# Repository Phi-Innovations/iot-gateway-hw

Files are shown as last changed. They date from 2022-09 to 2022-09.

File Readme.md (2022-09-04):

# IOT-GATEWAY-HW

This project contains the hardware design files of the IoT Gateway designed by PHI Innovations.

The hardware was designed using [Altium Designer](www.altium.com) tool.

# Features

* CPU: STM32F417VET6 Microncontroller
* 1 MB Dataflash
* MMC card support
* Debug UART interface
* 1 RS-485 interface
* 1 USB interface
* 1 Ethernet interface
* 1 WiFi module (ESP8266)
* 1 2G Modem (Sierra Wireless HL6528)
* 2 Digital inputs
* 2 Analog inputs (4-20 mA)
* 1 radio interface (never tested)

# TODO

- [ ] Improve documentation
- [ ] Add reset connection between CPU and the WiFi module

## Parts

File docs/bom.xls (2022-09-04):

BOM |  | PHI_IOT_GATEWAY_V1.3.PrjPcb |  | VER: | 08/03/2018
Item | Quantity | Designator | Comment | P Description | Fabricante 1 | Partnumber fabricante 1 | Partnumber Alternativo | PCB Info
1 | 1 | ANT1 | COAX-F | CONN SMA JACK R/A 50 OHM PCB | TE Connectivity AMP Connectors | 5-1814400-1
2 | 1 | ANT2 | 0915AT43A0026E | 915MHz Chip RF Antenna 902MHz ~ 928MHz | Johanson Technology Inc | 0915AT43A0026E
3 | 1 | ANT3 | U.FL RECEPTACLE | RECPT ULTRA-MINI COAX SMD | Hirose | U.FL-R-SMT-1
4 | 1 | BAT1 | BS-3 | HOLDER COINCELL 2032 RETAINR ARM | MPD | BS-3
5 | 27 | C2, C5, C6, C9, C10, C11, C12, C13, C14, C17, C21, C22, C27, C34, C39, C41, C47, C53, C54, C56, C58, C60, C61, C63, C64, C149, C162 | 0.1uF | Capacitor ceramico 0603 0.1uF 20% 50V X7R | AVX Corporation | 06035C104JAT2A | ‎C1608X5R1H104K080AA
6 | 8 | C3, C4, C15, C52, C65, C68, C77, C81 | 18pF | Capacitor ceramico 0603 18pF 5% 50V C0G | Murata Electronics North America | GRM1885C1H180JA01D
7 | 2 | C7, C8 | 2.2uF | Capacitor ceramico 0603 1uF 5% 25V X5R | Murata Electronics North America | GRM188R61E225MA12D
8 | 2 | C16, C18 | 0.01uF | Capacitor ceramico 0603 10000pF 10% 50V X7R | Kemet | C0603C103K5RACTU
9 | 2 | C19, C20 | 0.01uF | Capacitor ceramico 0603 10000pF 10% 50V X7R | Kemet | C0603C103K5RACTU |  | DNP
10 | 4 | C23, C24, C78, C83 | 1.5pF | Capacitor ceramico 0402 2.2pF 5% 50V C0G | Murata Electronics North America | GRM1555C1H1R5CA01D
11 | 2 | C25, C26 | 680uF 35V | CAP ALUM 680UF 20% 35V RADIAL | NIC Components Corp. | NREHL681M35V10x28F | UHW1V681MPD6
12 | 10 | C28, C29, C48, C50, C62, C123, C124, C150, C165, C167 | 10uF | Capacitor ceramico 0805 10uF 10% 10V X5R | AVX Corporation | 0805ZD106MAT2A | CL21A106KOQNNNE
13 | 11 | C30, C31, C32, C33, C35, C36, C37, C38, C163, C164, C166 | 33pF | Capacitor ceramico 0603 33pF 10% 50V C0G | Murata Electronics North America | GRM1885C1H330JA01D
14 | 1 | C40 | 0.015uF | Capacitor ceramico 0603 0.015uF 10% 50V X7R | Samsung Electro-Mechanics America, Inc | CL10B153KB8SFNC
15 | 5 | C42, C46, C70, C72, C85 | 0.47uF | Capacitor ceramico 0402 0.47uF 10% 10V X5R | Murata Electronics North America | GRM155R61A474KE15D | LMK105BJ474KV-F
16 | 2 | C43, C57 | 4.7uF | Capacitor ceramico 0603 4.7uF 10% 16V X7R | Samsung Electro-Mechanics America, Inc | CL10A475KO8NNNC
17 | 4 | C44, C75, C88, C90 | 0.15uF | Capacitor ceramico 0402 0.15uF 10% 10V X5R | Murata Electronics North America | GRM155R61A154KE19D | CGA2B3X5R1A154M050BB
18 | 12 | C45, C69, C71, C73, C74, C79, C80, C82, C84, C86, C89, C91 | 100pF | Capacitor ceramico 0402 100pF 5% 16V C0G | Murata Electronics North America | GRM1555C1H101JA01D | C0402C101J3GACTU
19 | 4 | C49, C59, C67, C76 | 1uF | Capacitor ceramico 0603 1uF 5% 25V X5R | Murata Electronics North America | GRM188R61E105KA12D
20 | 2 | C66, C87 | 470pF | Capacitor ceramico 0603 470pF 10% 50V X7R | Kemet | C0603C471K5RACTU
21 | 1 | C92 | 1.2pF | Capacitor ceramico 0402 1.2pF 20% 50V C0G | Murata Electronics North America | GRM1555C1H1R2CA01D
22 | 1 | C93 | 3.9pF | Capacitor ceramico 0402 3.9pF 2% 50V C0G | Murata Electronics North America | GJM1555C1H3R9BB01D
23 | 1 | C94 | 5.6pF | Capacitor ceramico 0402 5.6pF 5% 50V C0G | Murata Electronics North America | GRM1555C1H5R6CA01J
24 | 1 | C95 | 2.7pF | Capacitor ceramico 0402 2.7pF 5% 16V C0H | Samsung Electro-Mechanics America, Inc. | CL05C2R7CB5NNNC
25 | 1 | C97 | 0.5pF | Capacitor ceramico 0402 0.5pF 20% 50V C0G | Murata Electronics North America | GRM1555C1HR50BA01D
26 | 1 | C161 | 220uF 16V | CAP ALUM 220UF 20% 16V RADIAL | EPCOS | B41827A4227M007 | UVY1C221MED1TD
27 | 1 | CN1 | BLOCK - 5POS | TERM BLOCK HDR 5POS 90DEG 3.81MM | On Shore Technology Inc. | OSTOQ053251
28 | 1 | CN3 | BLOCK - 8POS | TERM BLOCK HDR 8POS 90DEG 3.81MM | On Shore Technology Inc. | OSTOQ083251
29 | 1 | CN4 | BLOCK - 2POS | TERM BLOCK HDR 2POS 90DEG 3.81MM | On Shore Technology Inc. | OSTOQ023251
30 | 2 | D1, D2 | BAT54C | Diodo Array Schottky Small Sig SOT-23-3 30V 1 Pair Common Cathode | Diodes Incorporated | BAT54C-7-F |  | DNP
31 | 3 | D3, D9, D11 | B360A-13-F | DIODE SCHOTTKY 60V 3A SMA | Diodes Incorporated | B360A-13-F
32 | 8 | D4, D6, D7, D10, D12, D13, D14, D15 | PESD3V3S1UB,115 | TVS DIODE 3.3VWM 20VC SOD523 | Nexperia USA Inc | PESD3V3S1UB,115 | ESD5Z3.3T1GOSCT-ND
33 | 1 | D5 | 0402ESDA | SUPPRESSOR ESD 30VDC 0402 HFREE | Eaton | 0402ESDA-MLP1
34 | 1 | D8 | BAT54C | Diodo Array Schottky Small Sig SOT-23-3 30V 1 Pair Common Cathode | Diodes Incorporated | BAT54C-7-F
35 | 2 | D16, D17 | CPDQR5V0 | TVS DIODE 5VWM 15VC 0402 | Comchip Technology | CPDQR5V0
36 | 4 | FB1, FB3, FB5, FB6 | 220R | Ferrite Bead Chip 0603 220OHM 2A 50mOHM | Murata Electronics North America | BLM18EG221SN1D
37 | 4 | J1, J2, J3, J4 | Jumper |  |  | Header 2.54mm
38 | 1 | J7 | RJ45_J1011F01PNL | CONN MAGJACK 1PORT 100 BASE-T | Pulse Eletronics | J1011F01PNL
39 | 2 | JP1, JP2 |  |  |  | Header 2.54mm
40 | 1 | L1 | 47uH | 47µH Shielded Wirewound Inductor 4.2A 108.9 mOhm Max 2-SMD, J-Lead | Panasonic Eletronic Components | ETQ-P5M470YFC
41 | 1 | L2 | 10uH | FIXED IND 10UH 100MA 780mOHM SMD | Taiyo Yuden | Murata Eletronics North America
42 | 2 | L3, L5 | 18nH | Indutor material nao especificado 0402 18nH 5% 400mA 0R360OHM | Murata Eletronics North America | LQG15HS18NJ02D
43 | 1 | L4 | 27nH | Indutor material nao especificado 0402 27nH 5% 350mA 460MOHM | Murata | LQG15HS27NJ02D
44 | 1 | L6 | 12nH | Indutor material nao especificado 0402 12nH 5% 400mA 0R350OHM | Murata Eletronics North America | LQG18HN12NJ00D
45 | 2 | L7, L11 | 4.3nH | Indutor material nao especificado 0402 4.3nH 5% 700mA 0R180OHM | Murata Eletronics North America | LQG15HS4N3S02D
46 | 1 | L8 | 6.2nH | FIXED IND 6.2NH 430MA 250 MOHM | Taiyo Yuden | HK10056N2S-T
47 | 1 | L9 | 5.6nH | Indutor material nao especificado 0402 5.6nH 5% 650mA 0R200OHM | Murata Eletronics North America | LQG15HS5N6S02D
48 | 1 | L10 | 10nH | Indutor material nao especificado 0402 10nH 5% 500mA 0R260OHM | Murata Eletronics North America | LQG15HS10NJ02D
49 | 5 | LD1, LD2, LD3, LD4, LD5 | LTST-S321KGKT | Standard LEDs - SMD Green 571nm 35mcd Clear | Lite-On | LTST-S321KGKT
50 | 2 | OP1, OP2 | FOD817A | OPTOISOLATOR 5KV TRANSISTOR 4SMD | Fairchild Semiconductor | FOD817A3SD
51 | 1 | P1 | LOADER |  |  | Header 2.54mm
52 | 1 | P2 | SIM CARD | DUAL SIM CONNECTOR | GCT | SIM6050-8-0-30-00-A
53 | 1 | P4 | USB-MICRO | CONN RCPT 5POS MICRO USB R/A | Molex | 47346-0001
54 | 1 | P5 | JST-B3BPHK | CONN HEADER PH TOP 3POS 2MM | JST | B3B-PH-K-S(LF)(SN)
55 | 1 | P6 | Header 6 |  |  | Header 2.54mm
56 | 1 | P8 | 47309-3351 | CONN MICRO SD CARD PUSH-PULL R/A | Molex | 47309-3351
57 | 8 | Q1, Q2, Q3, Q4, Q5, Q6, Q7, Q8 | PDTC123JT,235 | TRANS PREBIAS NPN 250MW TO236AB | NXP Semiconductors | PDTC123JT,235
58 | 2 | Q9, Q11 | IRLML6402 | MOSFET P CH SOT-23 20V 3.7A | Infineon Technologies Americas Corp | IRLML6402TRPBF | DMG2305UX-13
59 | 25 | R1, R2, R15, R17, R18, R19, R21, R28, R31, R35, R59, R62, R63, R64, R66, R67, R72, R76, R87, R96, R97, R98, R99, R100, R129 | 10K | Resistor SMD 0603 10K 1% 1/08W | Yageo | RC0603FR-0710KL
60 | 7 | R3, R5, R6, R8, R9, R10, R89 | 120R | Resistor SMD 0603 120R 1% 1/16W | Yageo | RC0603FR-07120RL
61 | 5 | R4, R54, R60, R61, R65 | 1.5K | Resistor SMD 0603 1.5K 1% 1/10W | Yageo | RC0603FR-071K5L
62 | 5 | R7, R74, R75, R88, R90 | 300R | Resistor SMD 0603 300R 5% 1/10W | Yageo | RC0603JR-07300RL
63 | 8 | R16, R23, R26, R29, R30, R32, R33, R85 | 1K | Resistor SMD 0603 1K 1% 1/10W | Yageo | RC0603FR-071KL
64 | 8 | R20, R34, R39, R40, R41, R42, R43, R44 | 0R | Resistor SMD 0603 0R JUMPER 1/10W | Yageo | RC0603JR-070RL
65 | 2 | R22, R25 | 100R | Resistor SMD 0603 100R 1% 1/16W | Yageo | RC0603FR-07100RL
66 | 2 | R24, R27 | 165R | Resistor SMD 0603 165R 1% 1/16W | Yageo | RC0603FR-07165RL
67 | 5 | R36, R38, R49, R50, R78 | 22R | Resistor SMD 0603 22R 1% 1/10W | Yageo | RC0603FR-0722RL
68 | 6 | R37, R86, R91, R92, R93, R94 | 0R | Resistor SMD 0402 0R 1% 1/16W | Yageo | RC0402JR-070RL
69 | 2 | R51, R58 | 1M | Resistor SMD 0603 1M 1% 1/10W | Yageo | RC0603FR-071ML
70 | 1 | R56 | 100K | Resistor SMD 0603 100K 1% 1/10W | Yageo | RC0603FR-07100KL
71 | 4 | R68, R69, R70, R71 | 49.9R | Resistor SMD 0603 49.9R 1% 1/16W | Yageo | RC0603FR-0749R9L
72 | 1 | R73 | 12K1 | Resistor SMD 0603 10K 1% 1/08W | Yageo | RC0603FR-0712K1L
73 | 1 | R84 | 2.61K | Resistor SMD 0603 2.61K 1% 1/10W | Yageo | RC0603FR-072K61L
74 | 1 | U1 | STM32F417VET6 | IC MCU 32BIT 512KB FLASH 100LQFP | STMicroelectronics | STM32F417VET6
75 | 1 | U2 | MX25L8006EM1I | IC FLASH 8MBIT 86MHZ 8SOP | Macronix | MX25L8006EM1I-12G
76 | 1 | U3 | MCP6032 | IC OPAMP GP 10KHZ RRO 8SOIC | Microchip Technology | MCP6032-E/SN
77 | 1 | U4 | PCF8563 | IC RTC CLK/CALENDAR I2C 8-SOIC | NXP | PCF8563T/5,518
78 | 1 | U5 | HL6528 | GSM MODEM GPRS | Sierra Wireless | HL6528-2.8VBR
79 | 1 | U6 | SN74AVC4T774PWR | IC BUS TRANSCVR 4BIT DL 16TSSOP | Texas Instruments | SN74AVC4T774PWR
80 | 1 | U8 | MAX1555EZK+TCT | IC BATT CHRGR LI+ 1CELL SOT23-5 | Maxim Integrated | MAX1555EZK+T
81 | 1 | U10 | QS3257 | IC MUX/DEMUX 2:1 CMOS 16-QSOP | IDT | QS3257QG8
82 | 1 | U12 | TMP175 |  | Texas Instruments | TMP175AIDR
83 | 1 | U13 | LAN8742A-CZ-TR | IC TXRX ETHERNET 100MBPS 24QFN | Microchip Technology | LAN8742A-CZ-TR
84 | 1 | U15 | ESP-WROOM-02 | TXRX ESP8266 MOD WIFI TRACE ANT | ESPRESSIF | ESP-WROOM-02
85 | 1 | U16 | LM2596 | IC REG MULT CONFIG INV ADJ D2PAK | ON Semiconductor | LM2596DSADJG
86 | 1 | U17 | AP2114H-3.3 | IC REG LDO 3.3V 1A SOT223 | Diodes Incorporated | AP2114H-3.3TRG1
87 | 1 | U18 | ST3485ECDR | IC TXRX RS485/422 250KBPS 8-SOIC | STMicroeletronics | ST3485ECDR | ISL83485IBZ-T
88 | 1 | U20 | S2-LPQTR | IC RF TxRx Only 802.15.4 24-VFQFN Exposed Pad | STMicroeletronics | S2-LPQTR
89 | 1 | X1 | 8MHZ | CRYSTAL 8.0000MHZ 20PF SMD | CTS-Frequency Controls | ATS08ASM-1
90 | 1 | X2 | 25MHZ | Cristal 4-SMD 18pF ±20ppm 25.000MHZ | Abracon LLC | ABM3B-25.000MHZ-B2-T
91 | 1 | X4 | 50MHZ | CRYSTAL 50.0000MHZ 18PF SMD | Abracon LLC | ABMM2-50.000MHZ-E2F-T
92 | 1 | Y3 | 32.7680kHz | Cristal 12.5pF ±20ppm 32.7680KHZ | Abracon LLC | AB38T-32.768KHZ-12.5

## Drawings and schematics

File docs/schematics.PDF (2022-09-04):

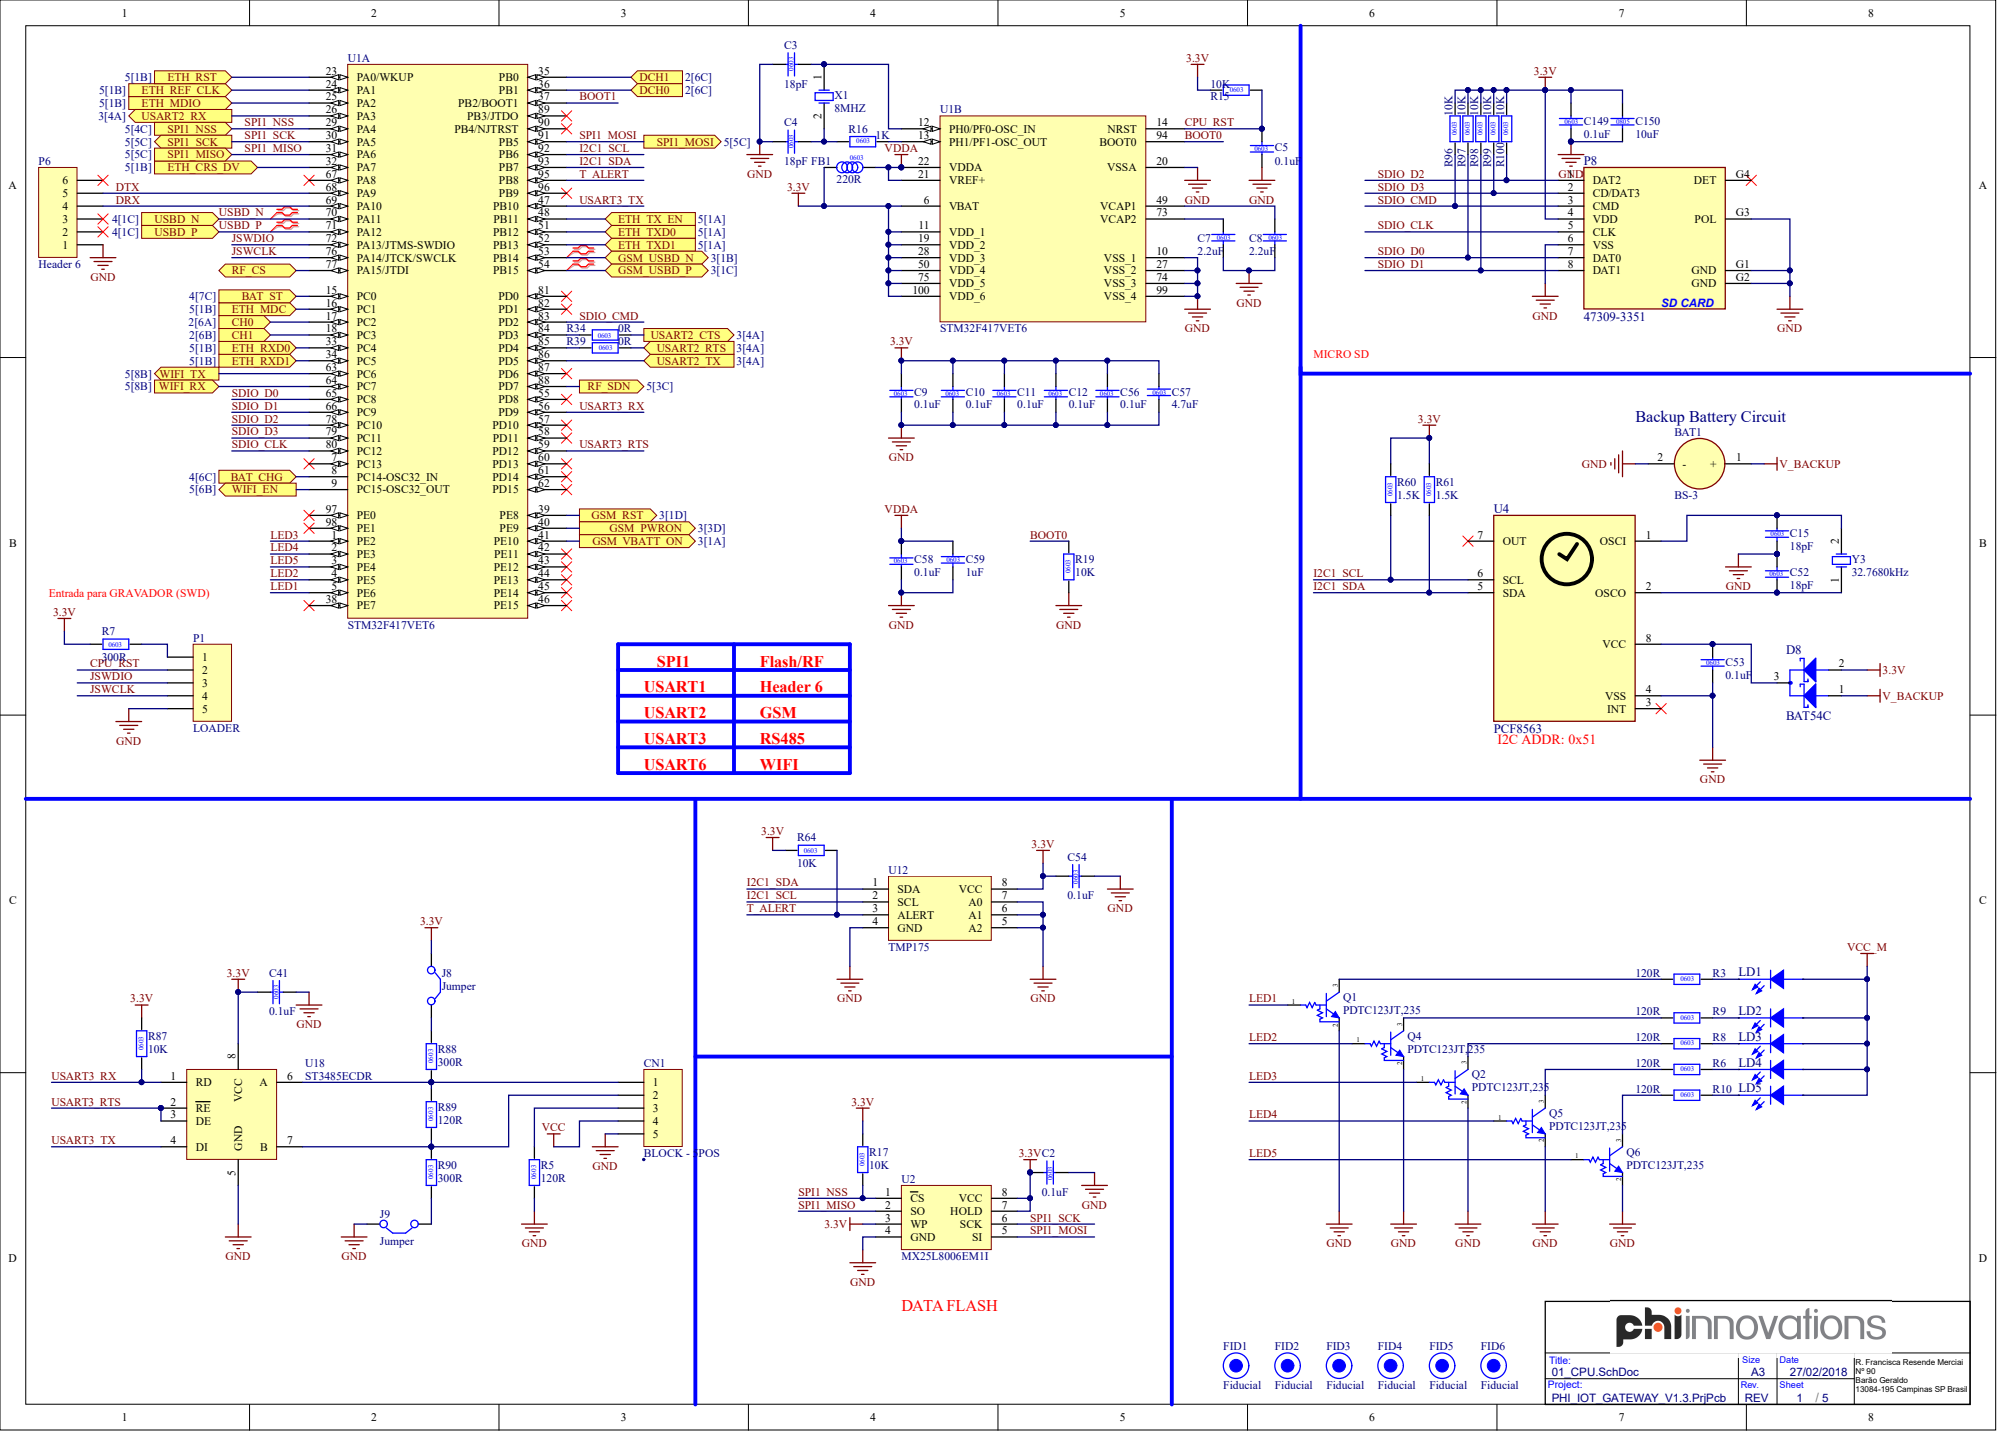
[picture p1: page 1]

Entrada para GRAVADOR (SWD)

USART1 | Header 6
USART2 | GSM
USART3 | RS485
USART6 | WIFI

Title: 01_CPU.SchDoc | Size A3 | Date 27/02/2018 | R. Francisca Resende Merciai Nº 90 Barão Geraldo 13084-195 Campinas SP Brasil

Project: PHI_IOT_GATEWAY_V1.3.PrjPcb | Rev. REV | Sheet 1 / 5

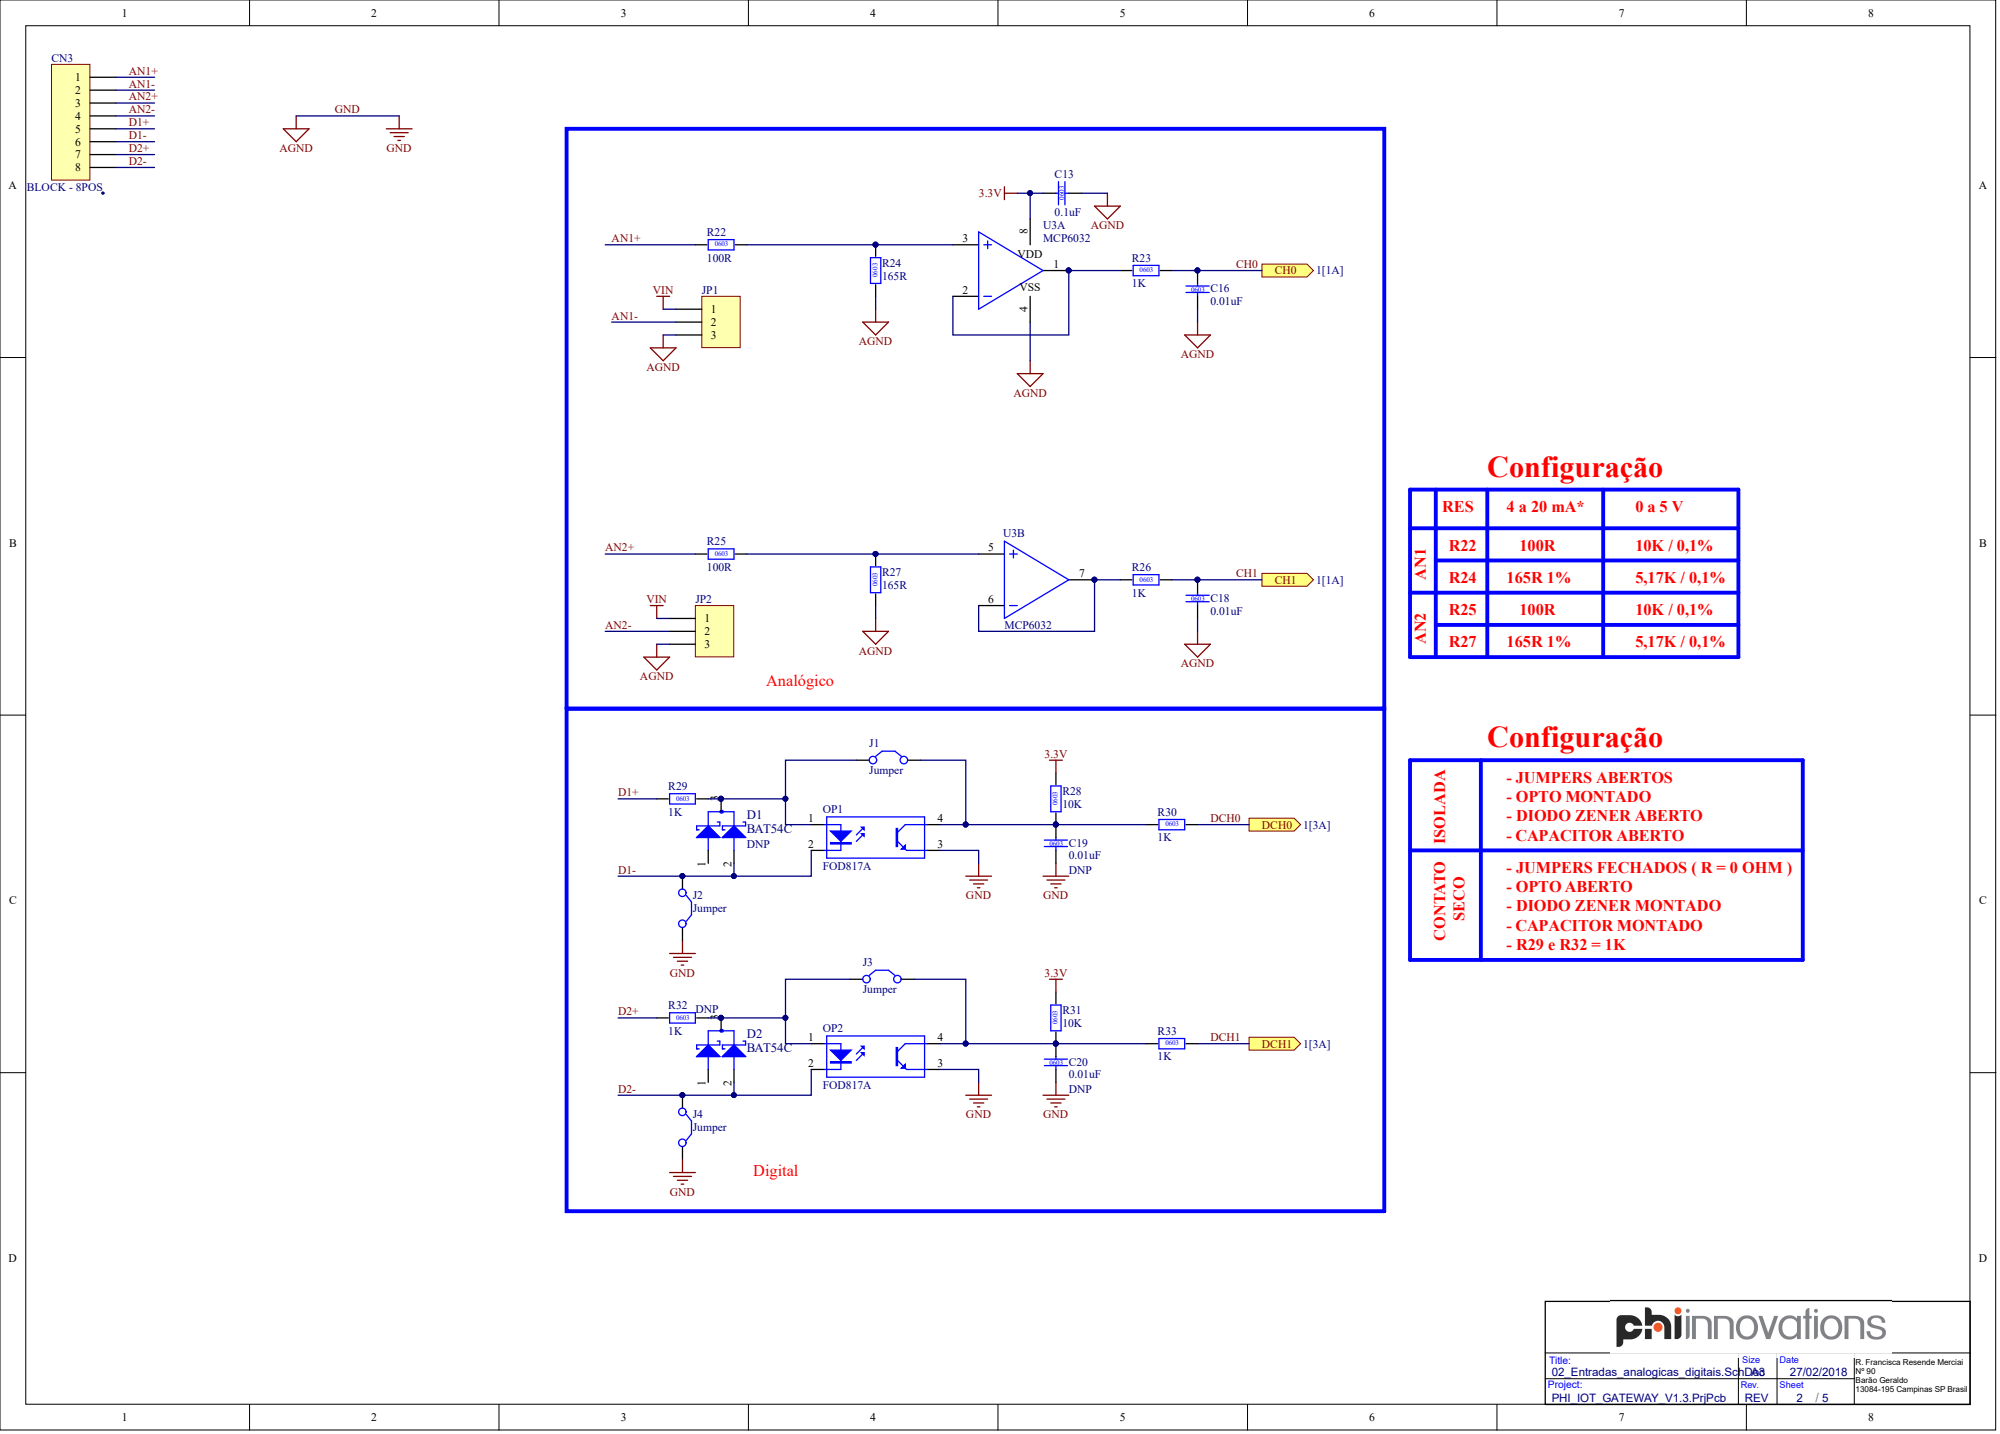
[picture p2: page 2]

RES | 4 a 20 mA* | 0 a 5 V

02_Entradas_analogicas_digitais.SchDoc | | 27/02/2018

REV | 2 5

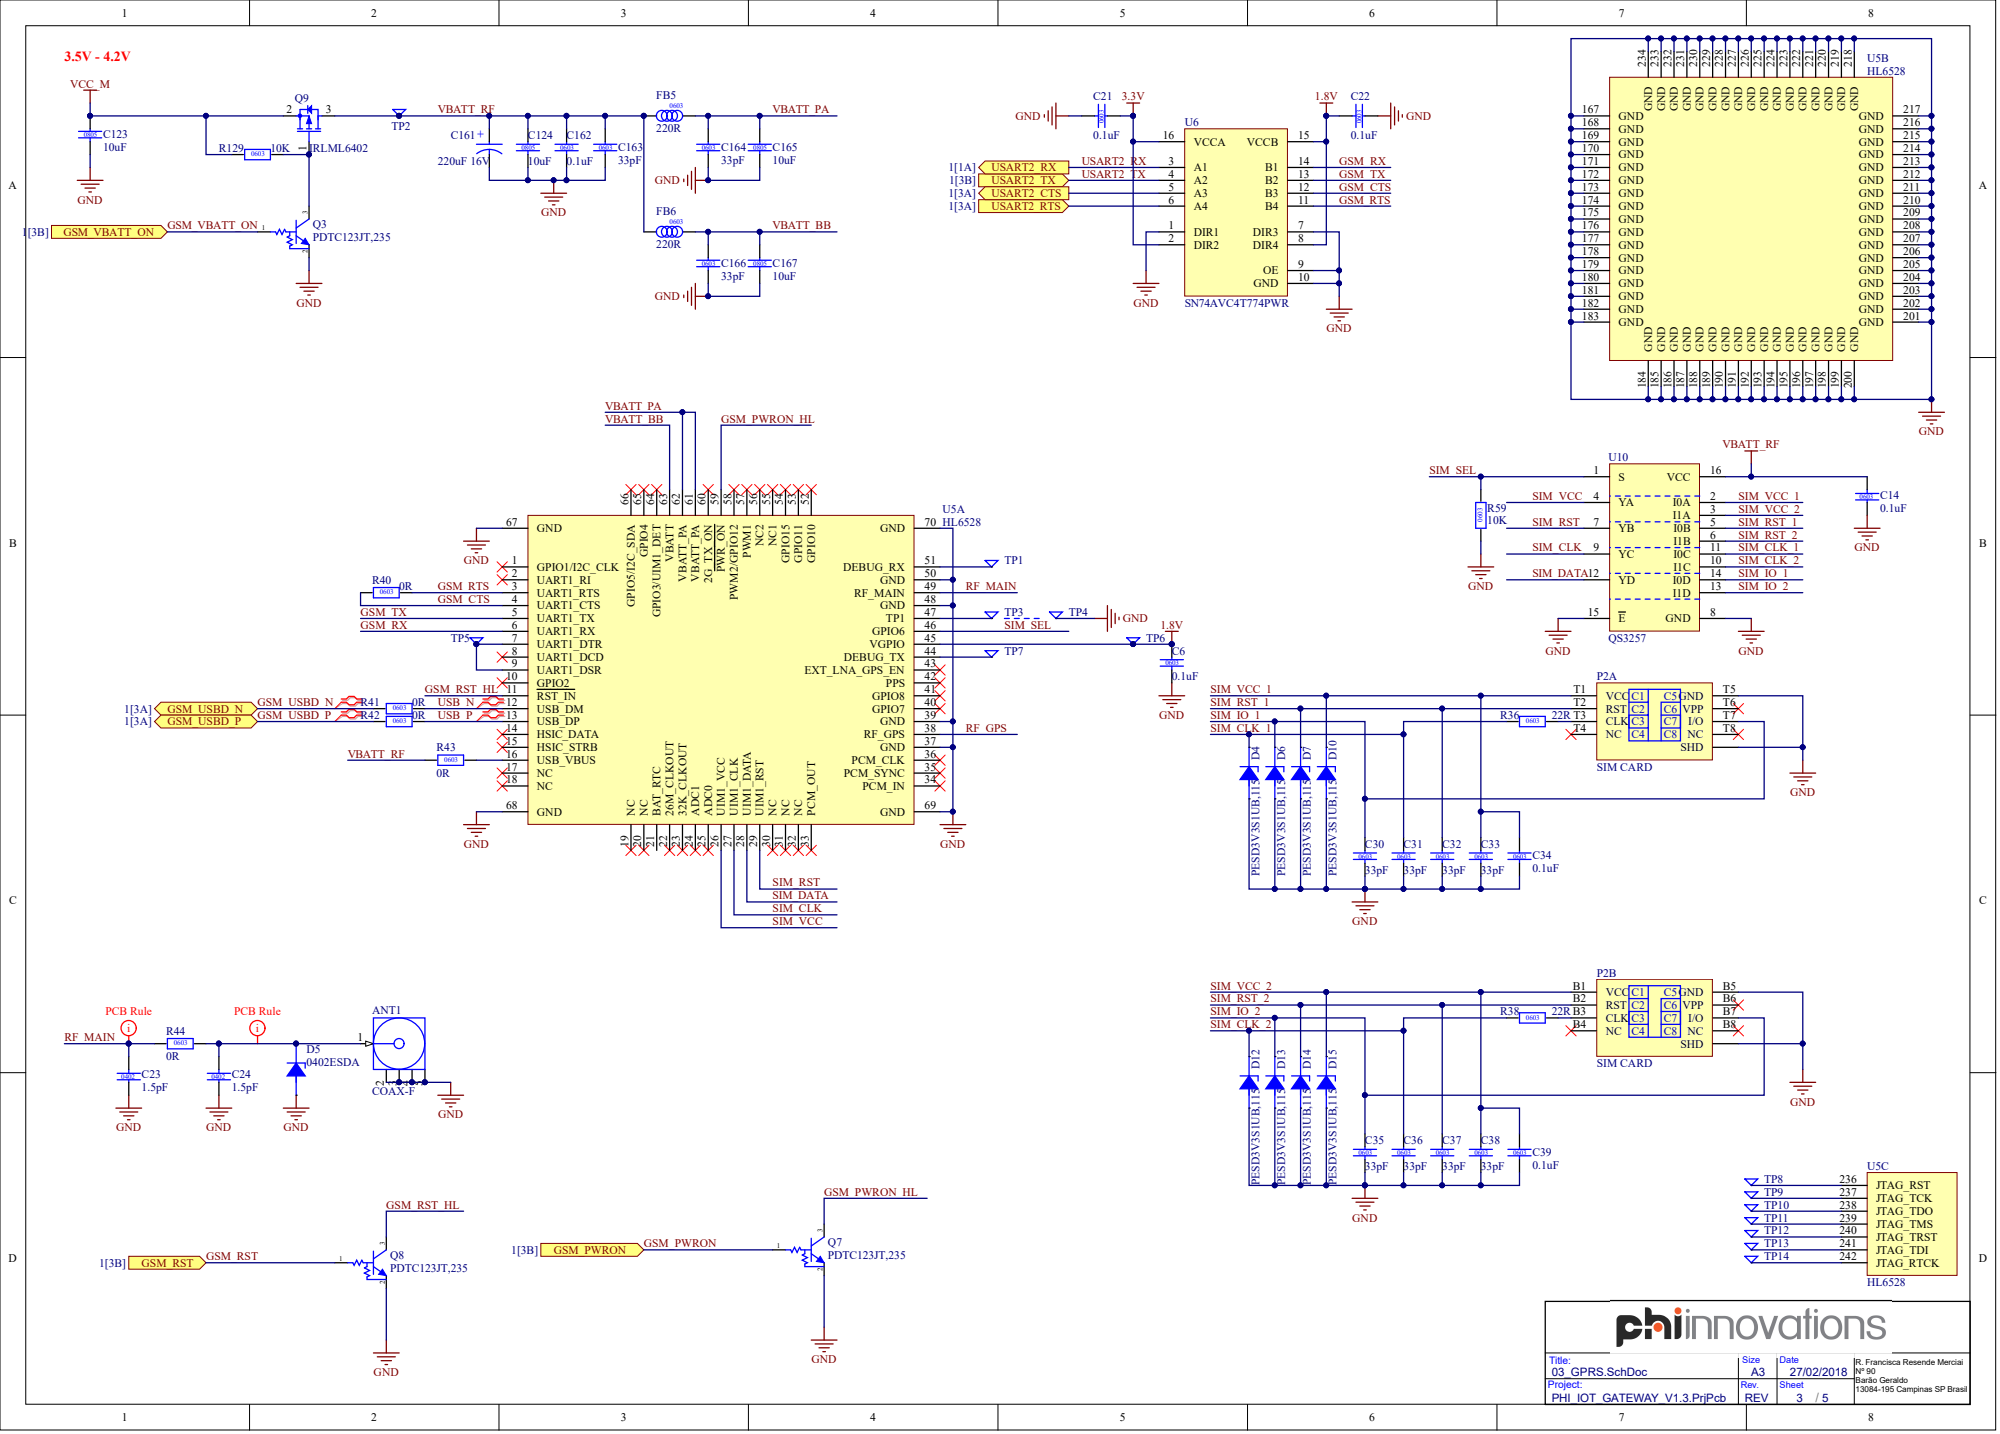
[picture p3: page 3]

217 ND 218 GND 219 GND 220 GND 221 GND 222 GND 223 GND 224 GND 225 GND 226 GND 227 GND 228 GND 229 GND 230 GND 231 GND 232 GND 233 GND 234

GND 200 GND 201 GND 202 GND 203 GND 204 GND 205 GND 206 GND 207 GND 208 GND 209 GND 210 GND 211 GND 212 GND 213 GND 214 GND 215 GND 216 GND

NC B4 CLK B3 RST B2 VCC B1

SIM_CLK_2

SHD

03_GPRS.SchDoc | | 27/02/2018

REV | 3 5

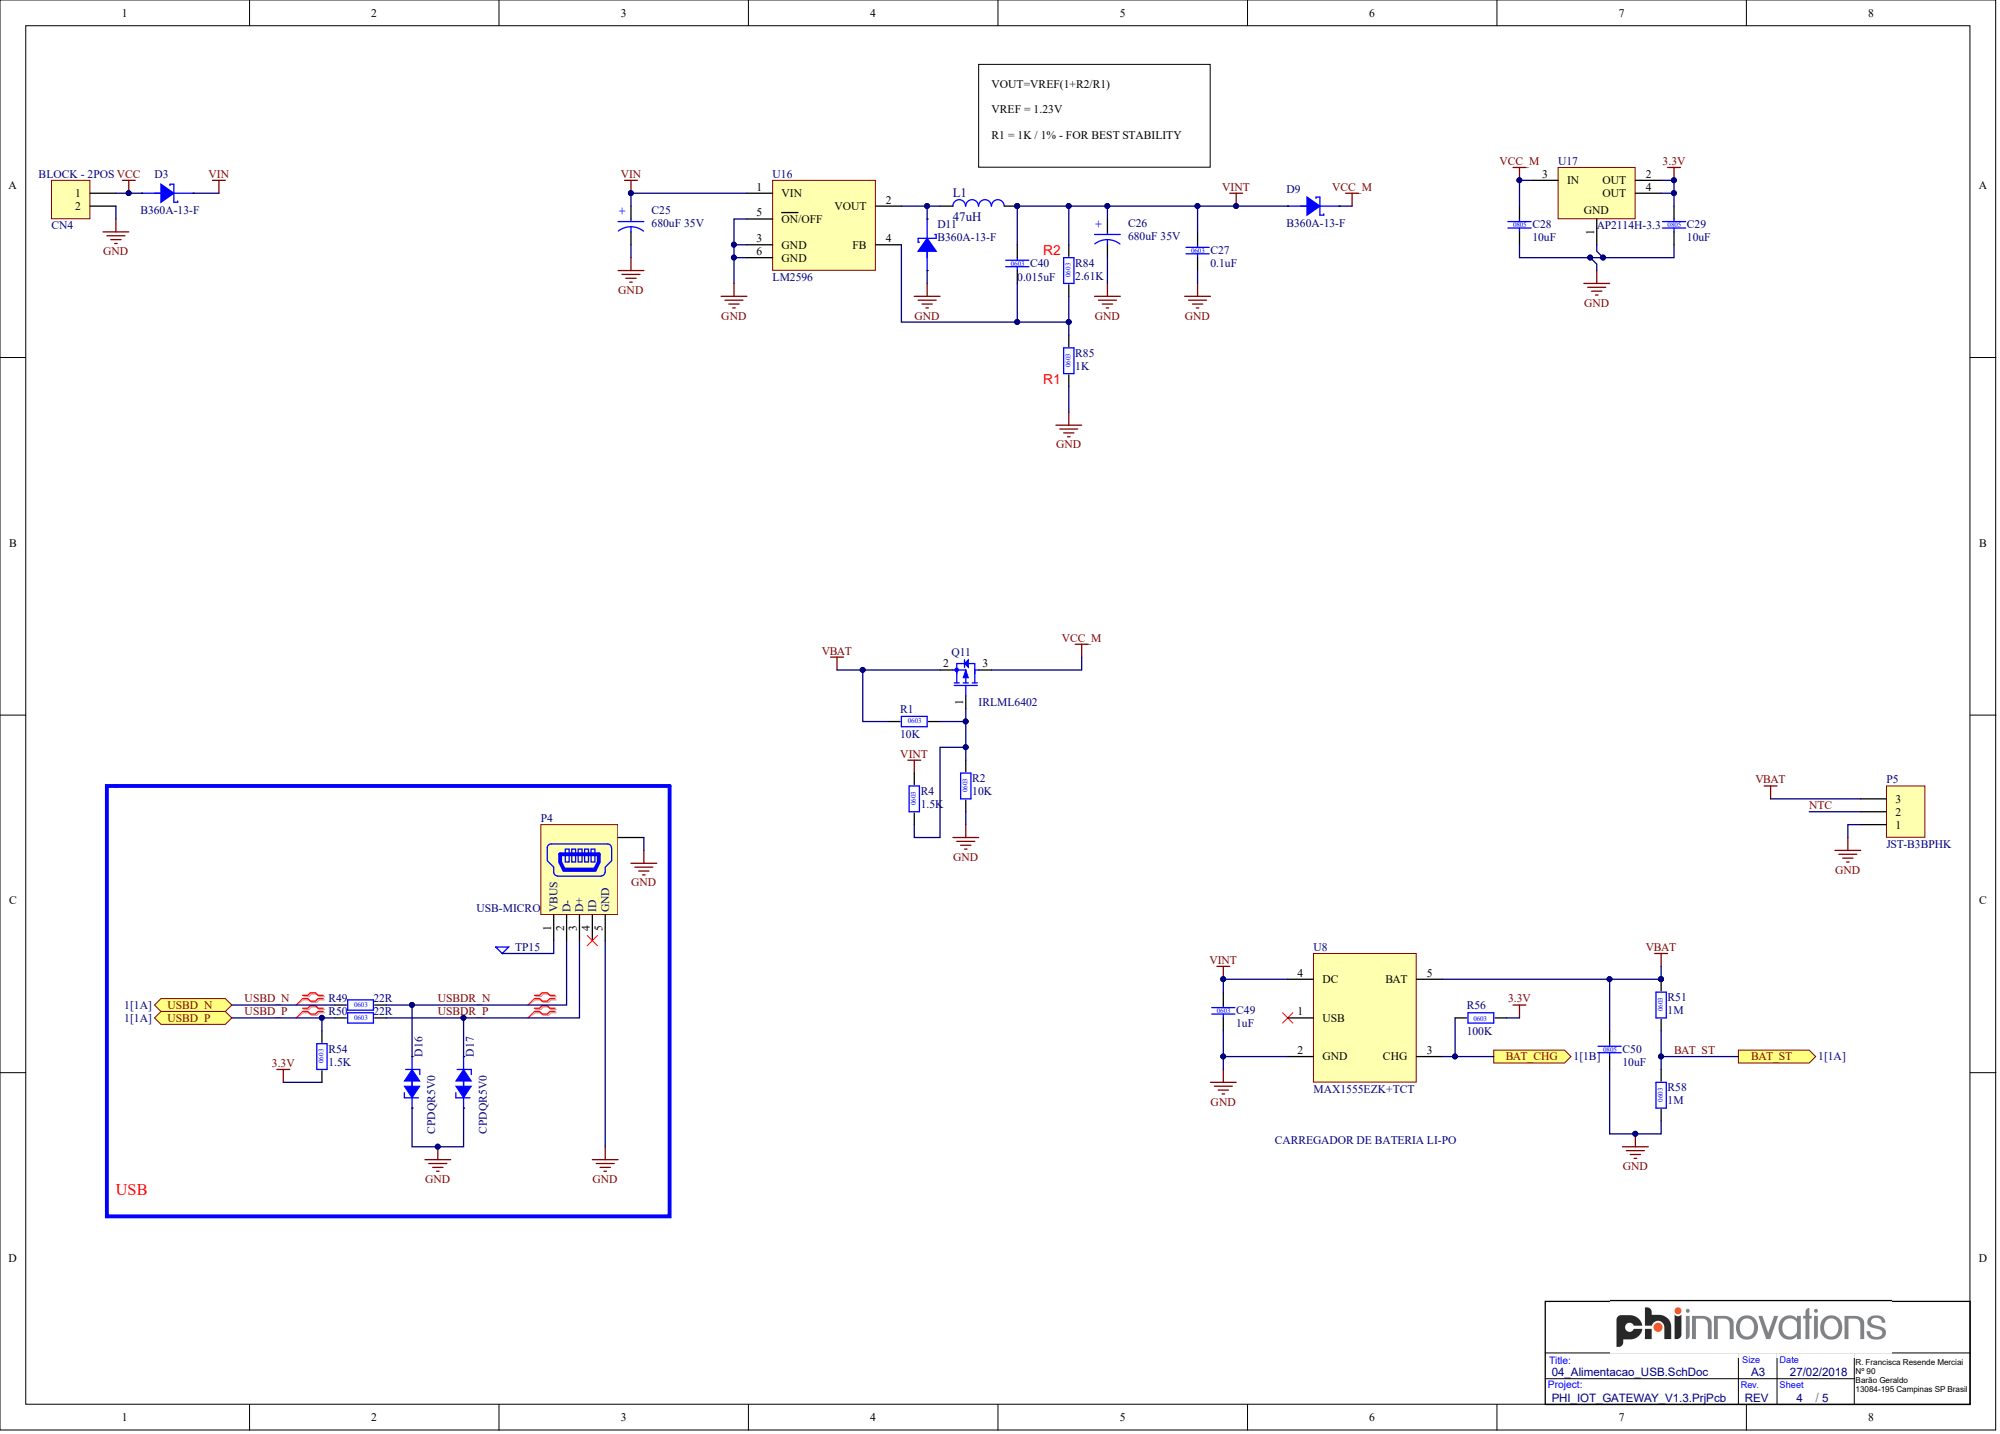
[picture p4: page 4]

CARREGADOR DE BATERIA LI-PO

04_Alimentacao_USB.SchDoc | | 27/02/2018

REV | 4 5

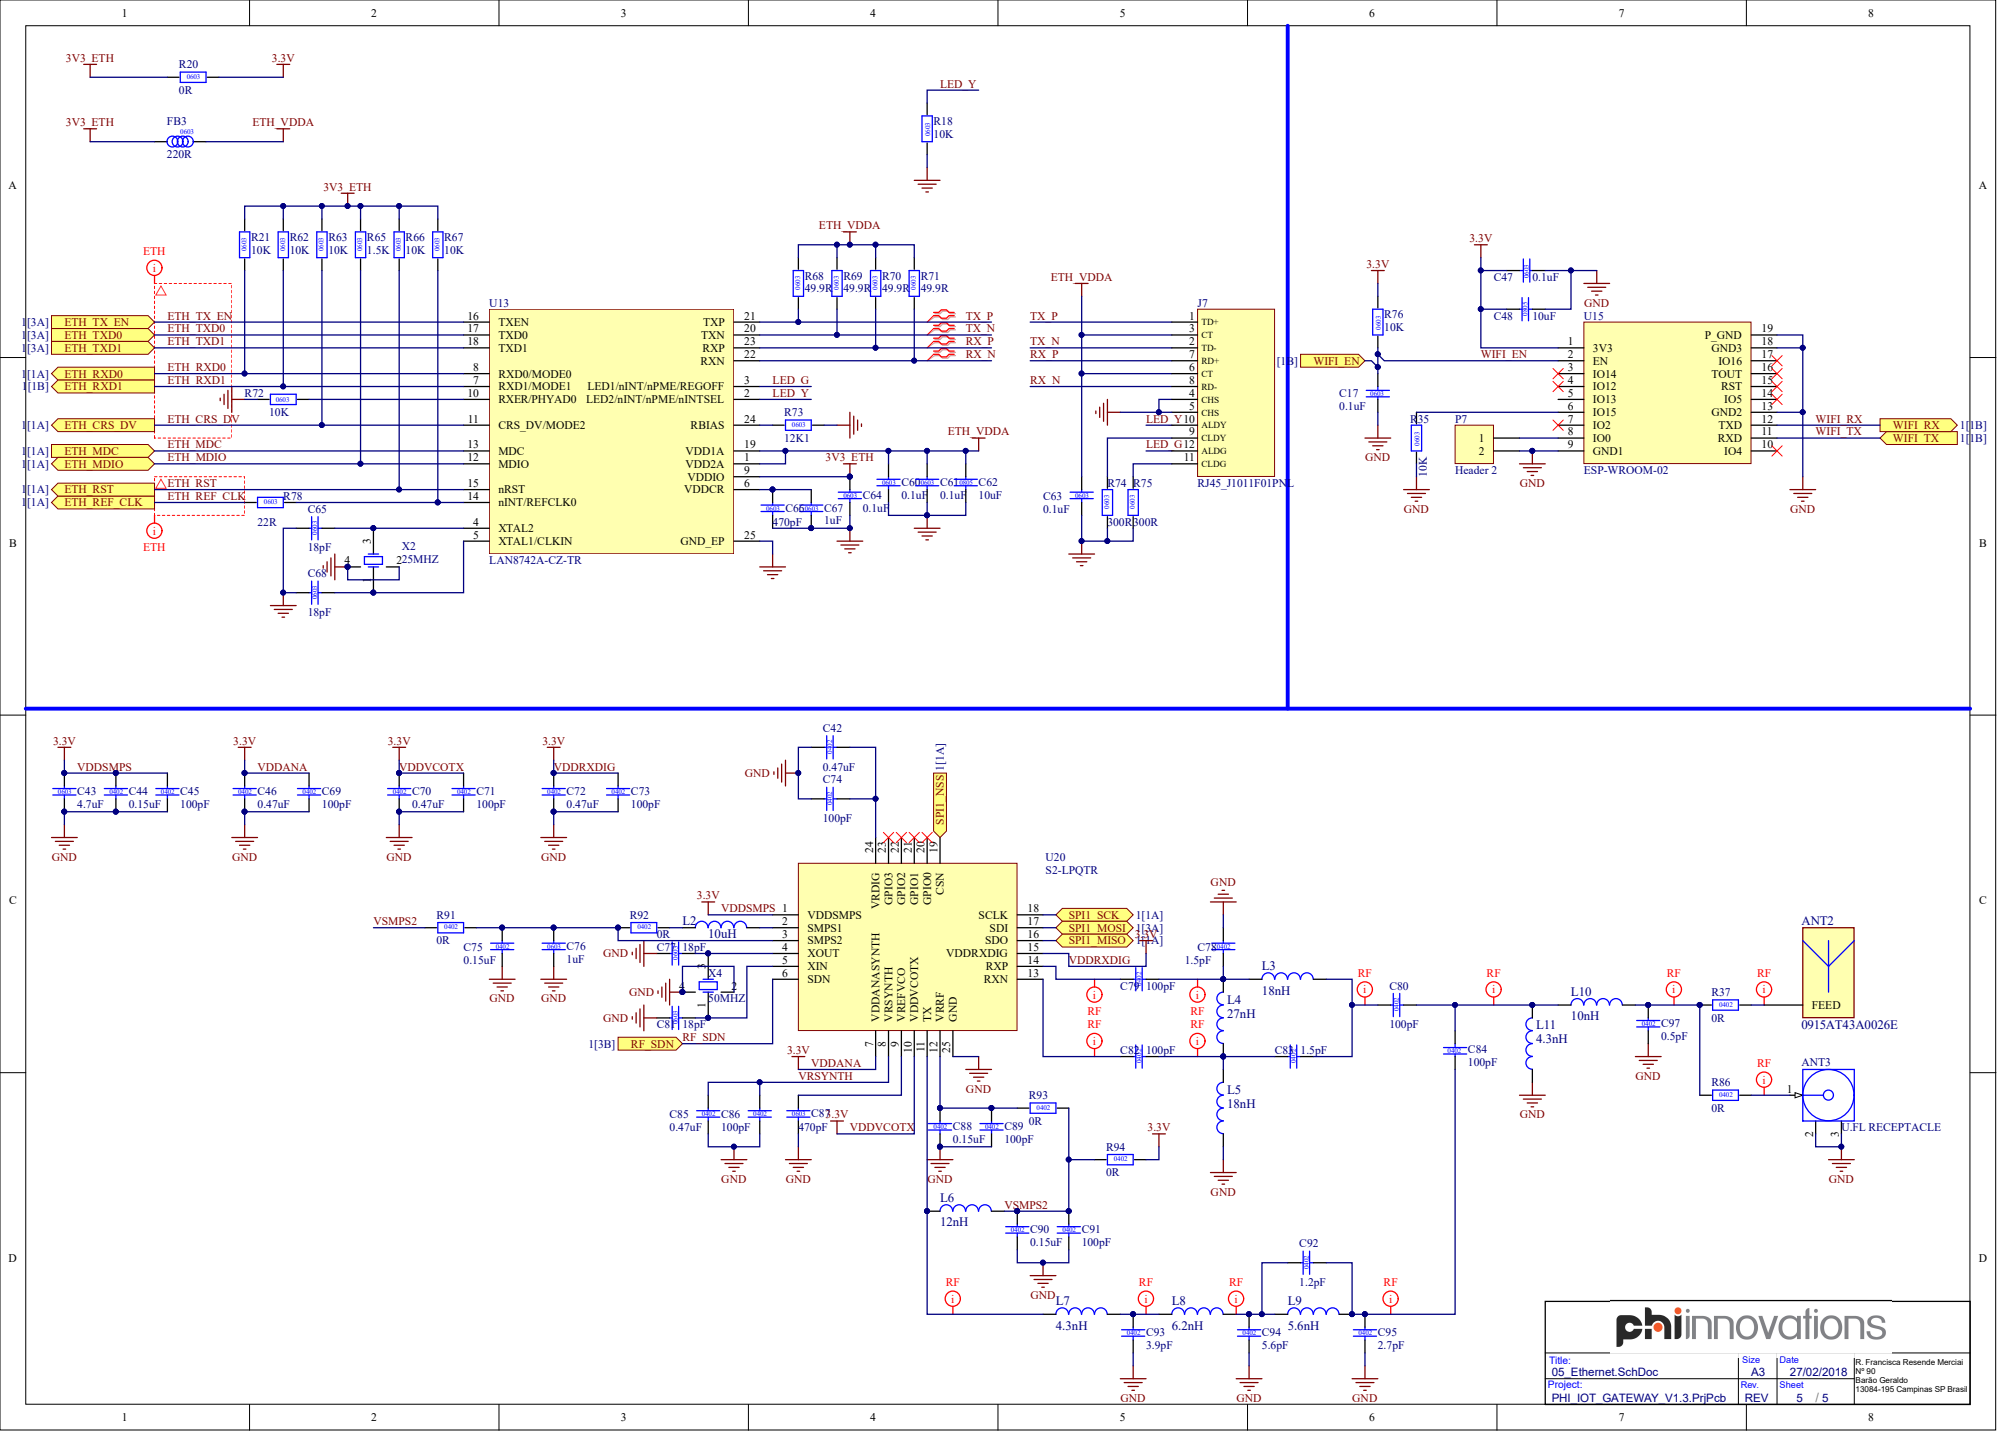
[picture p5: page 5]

C77 3 | 18pF | XOUT 4

X4 | | | SDN 6
4 | | | 2 | | | RF RF | i i | RF RF | i | L4 27nH
50MHZ

XIN 5 | | VDDRXDIG

VDDANA | | R93 | L5
VRSYNTH | GND

0402 C89 | VSMPS2 | 0402

05_Ethernet.SchDoc | | 27/02/2018

REV | 5 5

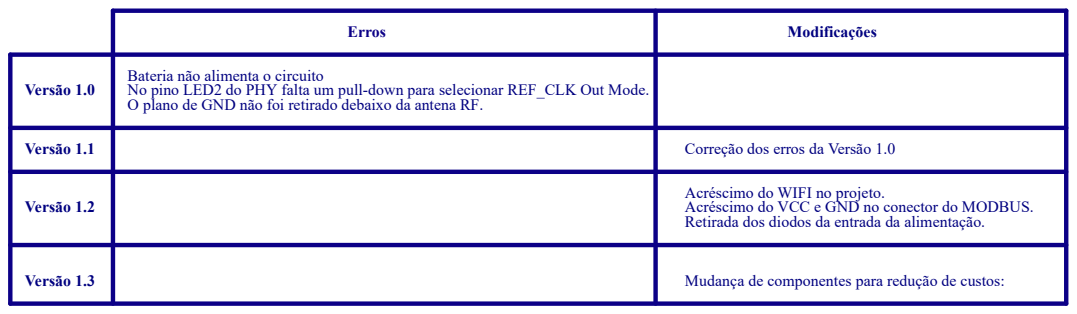
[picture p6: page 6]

Erros | Modificações

Versão 1.0 | Bateria não alimenta o circuito No pino LED2 do PHY falta um pull-down para selecionar REF_CLK Out Mode. O plano de GND não foi retirado debaixo da antena RF.

Versão 1.1 | | Correção dos erros da Versão 1.0

Versão 1.2 | | Acréscimo do WIFI no projeto. Acréscimo do VCC e GND no conector do MODBUS. Retirada dos diodos da entrada da alimentação.

Versão 1.3 | | Mudança de componentes para redução de custos:

Versoes.SchDoc | | 27/02/2018

REV | * *
